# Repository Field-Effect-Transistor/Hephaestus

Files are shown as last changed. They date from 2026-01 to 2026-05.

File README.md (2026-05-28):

***

# Hephaestus: Smart Soldering Station (T12 + 858D)

**Бакалаврська кваліфікаційна робота**  
Розробка мікрокомп'ютерної системи керування двоканальною паяльною станцією з прецизійним терморегулюванням та апаратною відмовобезпекою.






## 📋 Основні можливості
*   **Два незалежні канали:** Контактний паяльник (жало T12) та компресорний термофен (858D).
*   **Прецизійна точність:** ПІД-регулювання з використанням зовнішнього 16-бітного АЦП та підсилювачів Zero-Drift.
*   **Апаратна безпека:** Електромеханічне реле із системою "самопідхвату" для захисту від термічного пробою.
*   **Багатозадачність (RTOS):** Використання FreeRTOS із витискальною багатозадачністю для суворого дотримання таймінгів алгоритму часового розділення (Time-Division).
*   **HIL Simulation:** Архітектура коду (Dependency Inversion) дозволяє компілювати та тестувати бізнес-логіку станції як нативну Linux/PC програму (Симулятор).
*   **Інтерфейс:** 1.3" OLED дисплей (u8g2) та апаратне декодування квадратурних енкодерів.

## 🛠 Технічний стек

### Апаратна частина (Hardware)
*   **MCU:** STM32F103C8T6 (ARM Cortex-M3)
*   **ADC:** ADS1115 (16-bit, I2C, ΔΣ)
*   **OpAmp:** OPA2333 / MCP6002
*   **Power:** Багаторівнева система живлення (24V, 5V, 3.3V Digital, 3.3V Analog)
*   **Drivers:** MOSFET (T12 / Турбіна), Triac BTA16 + Optocoupler (Нагрівач 220В)
*   **EDA:** KiCad 8.0

### Програмна частина (Firmware)
*   **Language:** C++17 / C
*   **Framework:** STM32 HAL / LL
*   **OS:** FreeRTOS (ARM CM3 Port / POSIX Port для симулятора)
*   **Build System:** CMake + Ninja
*   **IDE:** Visual Studio Code (C/C++ Extension Pack)

## 📂 Структура репозиторію

```text
├── firmware/
│   ├── App/             # Бізнес-логіка, Інтерфейси (C++)
│   │   ├── interfaces/  # Апаратні абстракції (Hardware Agnostic)
│   │   ├── logic/       # ПІД-регулятор, автомати станів кнопок
│   │   ├── platform/    # Реалізація інтерфейсів (STM32 HAL або PC Mocks)
│   │   └── ui/          # Керування дисплеєм (u8g2)
│   ├── Core/            # Згенерований CubeMX код (main.c, freertos.c)
│   ├── Drivers/         # STM32 HAL & CMSIS
│   └── Libs/            # Сторонні бібліотеки (u8g2, FreeRTOS POSIX)
│
├── hardware/            # Схемотехніка та плати (KiCad)
└── docs/                # Пояснювальна записка та даташити
```

## 🚀 Як зібрати проєкт

Проєкт підтримує дві цілі збірки: **Прошивка для мікроконтролера (STM32)** та **Симулятор для комп'ютера (Linux/PC)**.

### 1. Збірка Симулятора (Linux)
Симулятор компілює всю бізнес-логіку, запускає FreeRTOS поверх Pthreads операційної системи Linux та імітує датчики за допомогою об'єктів-заглушок (Mocks). Це дозволяє тестувати систему без реальної плати.

**Вимоги:** `cmake`, `ninja`, `gcc`, `g++`.

```bash
cd firmware
mkdir -p build_pc
rm -rf build_pc/* 

# Генеруємо конфігурацію для симулятора
cmake -DBUILD_SIMULATOR=ON -DCMAKE_C_COMPILER=gcc -DCMAKE_CXX_COMPILER=g++ . -G Ninja -B build_pc   

# Збираємо проєкт
ninja -C build_pc 

# Запускаємо симулятор
./build_pc/Hephaestus_Sim
```

### 2. Збірка Прошивки (STM32)
Для крос-компіляції під мікроконтролер використовується офіційний Toolchain.

**Вимоги:** `arm-none-eabi-gcc`, `cmake`, `ninja`.

```bash
cd firmware
mkdir -p build
rm -rf build/*

# Генеруємо конфігурацію для крос-компіляції
cmake -DCMAKE_TOOLCHAIN_FILE=cmake/gcc-arm-none-eabi.cmake . -G Ninja -B build

# Збираємо прошивку (.elf, .bin, .hex)
ninja -C build
```

***

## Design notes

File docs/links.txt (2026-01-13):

https://www.datasheethub.com/wp-content/uploads/2022/08/SSD1306.pdf
https://www.alldatasheet.com/datasheet-pdf/view/328702/ALPS/EC11.html
https://documentation.espressif.com/esp32-s3_datasheet_en.html
https://github.com/wagiminator/ATmega-Soldering-Station/
https://www.alldatasheet.com/datasheet-pdf/pdf/195291/MICROCHIP/MCP6002-ISLASHSN.html
https://www.alldatasheet.com/datasheet-pdf/pdf/68872/IRF/IRLZ44N.html
https://www.alldatasheet.com/datasheet-pdf/pdf/22039/STMICROELECTRONICS/BTA16.html
https://www.alldatasheet.com/datasheet-pdf/pdf/292735/TI/ADS1115.html
https://www.alldatasheet.com/datasheet-pdf/view/1082481/TI1/LM358.html
https://www.ti.com/lit/ds/symlink/ads1115.pdf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

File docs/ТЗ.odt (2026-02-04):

# ТЕХНІЧНЕ ЗАВДАННЯ

Тема: Розробка апаратно-програмного комплексу двоканальної паяльної станції з підтримкою IoT-технологій та віддаленого керування.

Мета проєкту: Розробити прецизійний інструмент для монтажу та демонтажу електронних компонентів, що поєднує функціонал контактної пайки (стандарт T12) та термоповітряної пайки (фен 858D). Забезпечити високу точність підтримки температури за рахунок використання ПІД-алгоритмів та зовнішнього АЦП. Реалізувати концепцію IoT (Internet of Things) шляхом інтеграції веб-сервера для віддаленого моніторингу телеметрії, налаштування профілів та оновлення ПЗ.

Вимоги:

1. Апаратна платформа та сумісність:
  a. Головний контролер: Побудований на базі мікроконтролера архітектури ARM Cortex-M (STM32F103) для забезпечення роботи в реальному часі (Hard Real-Time).
  b. Мережевий шлюз: Використання модуля ESP8266 (ESP-07S) для забезпечення Wi-Fi з'єднання та хостингу вебу.
  c. Периферія: Підтримка змінних картриджів типу Hakko T12 та ручки термофену типу 858D (220В + 24В фен).
  d. Інтерфейс користувача: 1.23`` OLED-дисплей та подвійні енкодери.
2. Структура системи:
  a. Модуль керування (Control Unit - STM32):
    1. ПІД-регулятор температури (окремі контури для паяльника та фена).
    2. Драйвер дисплея та обробка енкодерів.
    3. Система безпеки (Watchdog, моніторинг помилок).
    4. UART-міст для обміну командами з ESP8266.
  b. Модуль комунікації (Gateway - ESP8266):
    1. HTTP-сервер (Web UI).
    2. UART-міст для обміну командами з STM32.
    3. OTA-менеджер.
  c. Аналогово-силова частина (PCB):
    1. Блок вимірювання (ADS1115 + ОП).
    2. Силові ключі (MOSFET для DC, Triac для AC).
    3. Схема захисного відключення.
3. Технологічний стек:
  a. Вбудоване ПЗ (Firmware): Мова C/C++. Середовище розробки VS Code + PlatformIO.
  b. Операційна система: FreeRTOS для STM32 та Arduino Core/Non-OS SDK для ESP8266.
  c. Схемотехніка: Проєктування електричної схеми та друкованої плати в САПР KiCad.
  d. Протоколи обміну: I2C (для сенсорів/дисплея), UART (міжпроцесорний зв'язок).
  e. Web-frontend: HTML, CSS3, JavaScript (бібліотека Chart.js для візуалізації графіків температури).
4. Вимірювання та точність:
  a. Для мінімізації шумів та підвищення розрядності вимірювань використовувати зовнішній 16-бітний АЦП (ADS1115).
  b. Реалізувати апаратну компенсацію холодного спаю (Cold Junction Compensation) з використанням NTC-термістора в ручці паяльника.
  c. Діапазон регулювання температур: 100°C – 450°C (для паяльника), 100°C – 500°C (для фена). Похибка стабілізації не більше ±5°C.
5. Функціональність сервера (ESP8266):
  a. Відображення поточного стану (температура, потужність, статус сну) в реальному часі через WebSocket.
  b. Надання інтерфейсу для зміни коефіцієнтів ПІД (Kp, Ki, Kd) "на льоту".
  c. Логування графіків нагріву для аналізу перехідних процесів.
  d. Можливість віддаленого оновлення прошивки як ESP, так і STM32 (через UART).
6. Безпека та захист:
  a. Hardware: Реалізація схеми "самопідхвату" живлення на базі реле. При зависанні МК або аварійній ситуації живлення має фізично вимикатися до ручного перезапуску.
  b. Software: Алгоритмічний захист від перегріву (Runaway protection) — відключення нагріву, якщо температура не зростає при подачі потужності (обрив датчика).
  c. Гальванічна розв'язка ланцюгів 220В (через оптопари з Zero-Cross).

# Мінімальний життєздатний продукт (MVP)

Мета MVP: Створити повністю функціональний пристрій, здатний виконувати задачі пайки та демонтажу з керуванням через фізичні енкодери та базовим відображенням параметрів у веб-інтерфейсі.

Функціональні вимоги MVP:

1. Стабільна робота ПІД-регуляторів для обох каналів (T12 та 858D).
2. Коректна робота силової частини: керування нагрівачем фена (220В), вентилятором та паяльником (24В).
3. Реалізація режимів сну (Sleep Mode) при бездіяльності інструменту (датчик вібрації/геркон).
4. Базовий веб-інтерфейс: відображення поточної та заданої температури.
5. Робоча схема захисного реле (увімкнення/вимкнення кнопкою без фіксації).

Потенційні напрямки розвитку

Мета: Розширення можливостей для лабораторного використання та інтеграції в систему "Розумний дім".

- Інтеграція: Додавання підтримки протоколу MQTT для підключення до Home Assistant.
- Профілі пайки: Створення бібліотеки термопрофілів для різних типів припоїв та жал.
- Діагностика: Реалізація системи самодіагностики споживання струму та напруги БЖ.
- Мобільний додаток: Створення нативного додатку замість веб-інтерфейсу.

Кроки реалізації продукту

- Етап 1 (Hardware): Розробка схеми в KiCad, розведення плати, замовлення компонентів, монтаж плати (Soldering), перевірка силових вузлів.
- Етап 2 (Firmware - Low Level): Написання драйверів для STM32 (ADS1115, I2C, UART, PWM, GPIO) з використанням регістрів/HAL та FreeRTOS.
- Етап 3 (Control Logic): Реалізація та налаштування ПІД-регулятора, калібрування АЦП.
- Етап 4 (Connectivity): Розробка прошивки для ESP8266, створення веб-інтерфейсу, налаштування обміну даними між чіпами.
- Етап 5 (Integration): Збірка в корпус, фінальне тестування, написання дипломної документації.

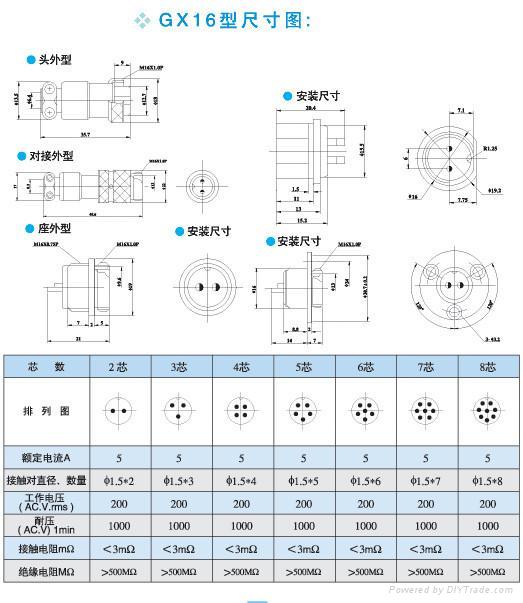
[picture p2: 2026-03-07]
docs/datasheets/GX16.jpg

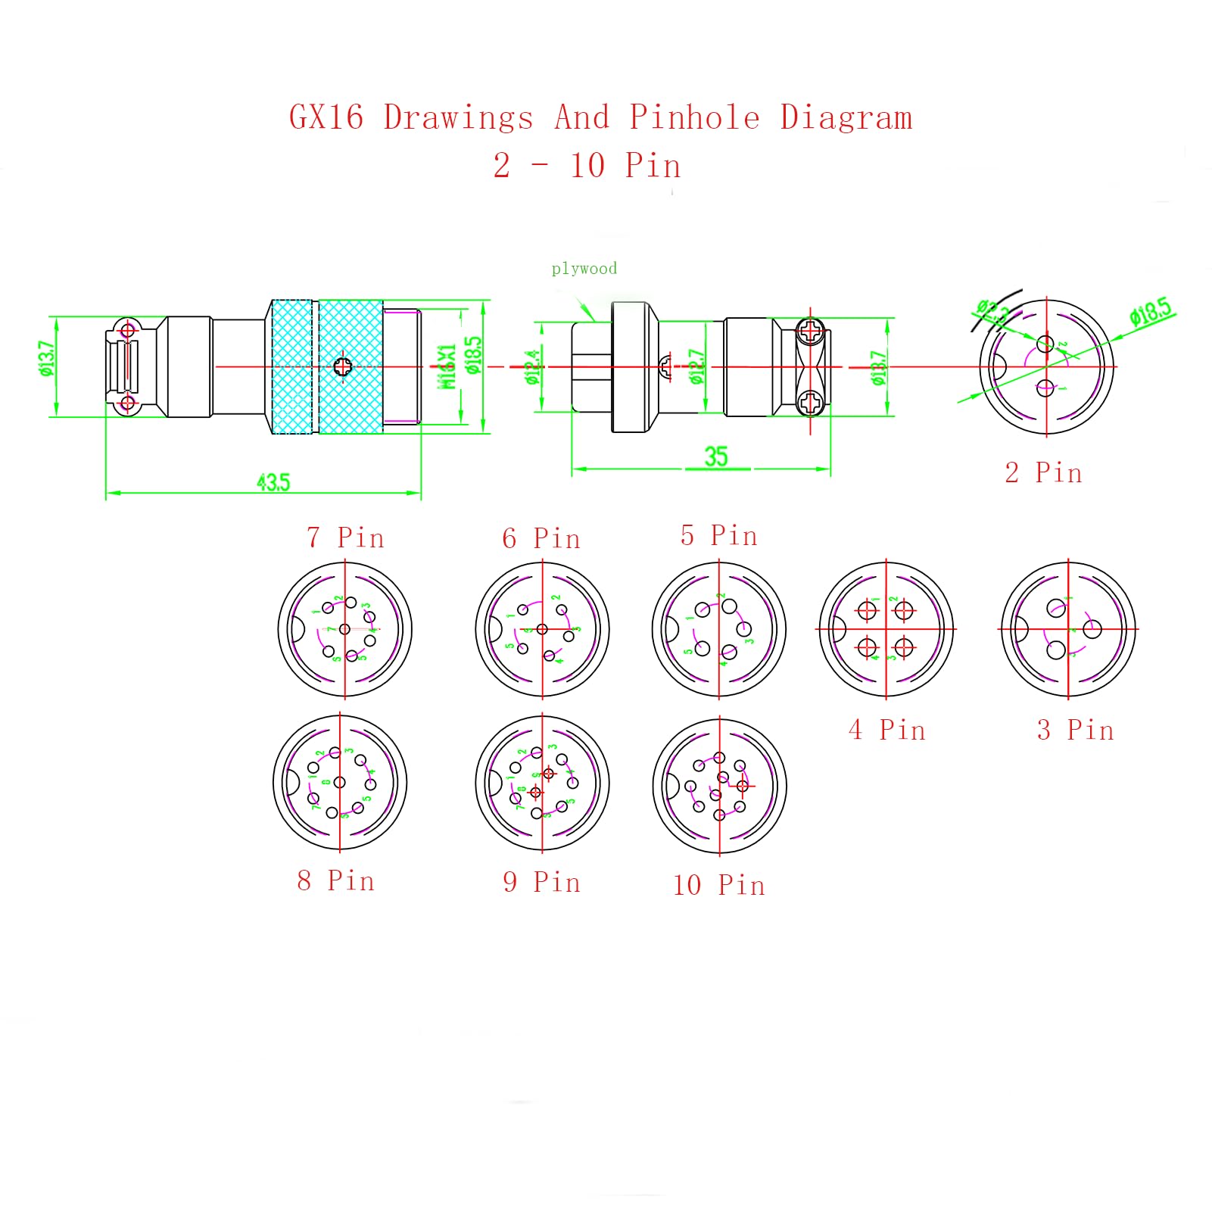
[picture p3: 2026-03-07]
docs/datasheets/71A6K6x6qkL.jpg

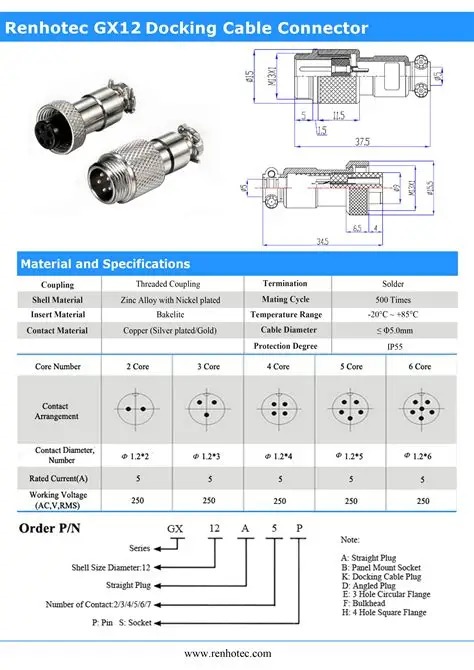
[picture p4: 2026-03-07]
docs/datasheets/OIP.webp

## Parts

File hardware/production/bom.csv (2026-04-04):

Designator | Footprint | Quantity | Value | LCSC Part #
BZ1 | Buzzer_12x9.5RM7.6 | 1 | Buzzer
C1, C12, C14, C15, C16, C17, C18, C19, C2, C20, C6, C7, C8 | 0805 | 13 | 0.1u | C14663
C10, C9 | 0805 | 2 | 22pF | C1653
C11, C21 | CP_Radial_D6.3mm_P2.50mm | 2 | 100uF
C13, C3 | CP_Radial_D5.0mm_P2.00mm | 2 | 10uF
C4 | 1206 | 1 | 10uF | C13585
C5 | 0805 | 1 | 1uF | C1634
C8_2 | CP_EIA-3216-18_Kemet-A | 1 | 22uF
D1, D2 | D_SMA | 2 | SS54 | C22452
D3 | D_DO-35_SOD27_P2.54mm_Vertical_AnodeUp | 1 | BZT52C12
D4 | D_SOD-123F | 1 | 1N4148 | C2128
D5 | D_DO-35_SOD27_P2.54mm_Vertical_AnodeUp | 1 | BZT52C3V3
D6, D7, D8 | 0805 | 3 | LED | C2286
GX12 | GX-12-5 | 1 | Soldering Iron
GX16 | GX-16-8 | 1 | Hot Air
J1 | TerminalBlock_MaiXu_MX126-5.0-03P_1x03_P5.00mm | 1 | AC Screw Terminal
J10 | TerminalBlock_MaiXu_MX126-5.0-03P_1x03_P5.00mm | 1 | Power
J11, J9 | PinHeader_1x02_P2.54mm_Vertical | 2 | Logic
J12 | PinHeader_1x04_P2.54mm_Vertical | 1 | SWD
J13 | TerminalBlock_MaiXu_MX126-5.0-02P_1x02_P5.00mm | 1 | Relay Contact
J14 | TerminalBlock_MaiXu_MX126-5.0-02P_1x02_P5.00mm | 1 | Relay Coil
J2 | PinHeader_1x05_P2.54mm_Vertical | 1 | Iron Encoder
J3 | PinHeader_1x05_P2.54mm_Vertical | 1 | Hot Air Encoder
J4 | PinHeader_1x04_P2.54mm_Vertical | 1 | OLED
J5 | TerminalBlock_MaiXu_MX126-5.0-02P_1x02_P5.00mm | 1 | High Voltage
J6 | PinHeader_1x04_P2.54mm_Vertical | 1 | UART
J7 | PinHeader_1x03_P2.54mm_Vertical | 1 | STM BOOT
J8 | TerminalBlock_MaiXu_MX126-5.0-03P_1x03_P5.00mm | 1 | +5V
JP1 | PinHeader_1x03_P2.54mm_Vertical | 1 | Jumper_2_Open
Q1, Q4 | TO-220-3_Vertical | 2 | IRLZ44N
Q2, Q3, Q5 | TO-92_Inline | 3 | 2N2222 | C2146
Q7 | TO-220-3_Vertical | 1 | BTA16-600B
R1, R3 | 0805 | 2 | 300 | C23025
R10, R16 | R_Axial_DIN0207_L6.3mm_D2.5mm_P7.62mm_Horizontal | 2 | 3k
R11, R39 | 0805 | 2 | 2.2k | C4190
R12, R15, R17, R18, R19, R20, R22, R23, R29, R30, R31, R32, R33, R34, R35, R38, R41, R42 | 0805 | 18 | 1k | C21190
R13, R14, R2, R21, R26, R28, R36, R37, R40, R6, R7, R8, R9 | 0805 | 13 | 10k | C25804
R24, R27 | 0805 | 2 | 100k | C25803
R25 | 0805 | 1 | 200k | C25811
R4, R5 | R_Axial_DIN0309_L9.0mm_D3.2mm_P12.70mm_Horizontal | 2 | 390/0.5W
SW1 | SW_PUSH_6mm_H8mm | 1 | SW_SPST
SW2 | TerminalBlock_MaiXu_MX126-5.0-02P_1x02_P5.00mm | 1 | SW_SPST
SW3 | PinHeader_1x02_P2.54mm_Vertical | 1 | SW_SPST
U1 | DIP-6_W7.62mm_LongPads | 1 | MOC3063M
U2, U4 | SOT-223-3_TabPin2 | 2 | AMS1117-3.3 | C6186
U5 | LQFP-48_7x7mm_P0.5mm | 1 | STM32F103C8Tx
U6 | SOIC-8_3.9x4.9mm_P1.27mm | 1 | MCP6002-xSN
U7 | MSOP-10_3x3mm_P0.5mm | 1 | ADS1115
Y1 | Crystal_SMD_5032-2Pin_5.0x3.2mm | 1 | X50328MSB2GI | C115962

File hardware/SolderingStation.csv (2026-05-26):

Reference | Value | Qty | LCSC | Footprint
C9,C10 | 22pF | 2 | C1653 | Capacitor_SMD:C_0805_2012Metric_Pad1.18x1.45mm_HandSolder
C1,C2,C6,C7,C8,C12,C14,C15,C16,C17,C18,C19,C20 | 0.1u | 13 | C14663 | Capacitor_SMD:C_0805_2012Metric_Pad1.18x1.45mm_HandSolder
C5 | 1uF | 1 | C1634 | Capacitor_SMD:C_0805_2012Metric_Pad1.18x1.45mm_HandSolder
C3,C13 | 10uF | 2 |  | Capacitor_THT:CP_Radial_D5.0mm_P2.00mm
C4 | 10uF | 1 | C13585 | Capacitor_SMD:C_1206_3216Metric
C11,C21 | 100uF | 2 |  | Capacitor_THT:CP_Radial_D6.3mm_P2.50mm
R1,R3 | 300 | 2 | C23025 | Resistor_SMD:R_0805_2012Metric_Pad1.20x1.40mm_HandSolder
R12,R15,R17,R18,R19,R20,R22,R23,R29,R30,R31,R32,R33,R34,R35,R38,R41,R42 | 1k | 18 | C21190 | Resistor_SMD:R_0805_2012Metric_Pad1.20x1.40mm_HandSolder
R11,R39 | 2.2k | 2 | C4190 | Resistor_SMD:R_0805_2012Metric_Pad1.20x1.40mm_HandSolder
R10,R16 | 3k | 2 |  | Resistor_THT:R_Axial_DIN0207_L6.3mm_D2.5mm_P7.62mm_Horizontal
R2,R6,R7,R8,R9,R13,R14,R21,R26,R28,R36,R37,R40 | 10k | 13 | C25804 | Resistor_SMD:R_0805_2012Metric_Pad1.20x1.40mm_HandSolder
R24,R27 | 100k | 2 | C25803 | Resistor_SMD:R_0805_2012Metric_Pad1.20x1.40mm_HandSolder
R25 | 200k | 1 | C25811 | Resistor_SMD:R_0805_2012Metric_Pad1.20x1.40mm_HandSolder
J8 | +5V | 1 |  | TerminalBlock:TerminalBlock_MaiXu_MX126-5.0-03P_1x03_P5.00mm
D4 | 1N4148 | 1 | C2128 | Diode_SMD:D_SOD-123F
Q2,Q3,Q5 | 2N2222 | 3 | C2146 | Package_TO_SOT_THT:TO-92_Inline
R4,R5 | 390/0.5W | 2 |  | Resistor_THT:R_Axial_DIN0309_L9.0mm_D3.2mm_P12.70mm_Horizontal
J1 | AC Screw Terminal | 1 |  | TerminalBlock:TerminalBlock_MaiXu_MX126-5.0-03P_1x03_P5.00mm
U7 | ADS1115 | 1 |  | Package_SO:MSOP-10_3x3mm_P0.5mm
U2,U4 | AMS1117-3.3 | 2 | C6186 | Package_TO_SOT_SMD:SOT-223-3_TabPin2
Q7 | BTA16-600B | 1 |  | Package_TO_SOT_THT:TO-220-3_Vertical
BZ1 | Buzzer | 1 |  | Buzzer_Beeper:Buzzer_12x9.5RM7.6
D3 | BZT52C12 | 1 |  | Diode_THT:D_DO-35_SOD27_P2.54mm_Vertical_AnodeUp
D5 | BZT52C3V3 | 1 |  | Diode_THT:D_DO-35_SOD27_P2.54mm_Vertical_AnodeUp
J5 | High Voltage | 1 |  | TerminalBlock:TerminalBlock_MaiXu_MX126-5.0-02P_1x02_P5.00mm
GX16 | Hot Air | 1 |  | SolderingStationLib:GX-16-8
J3 | Hot Air Encoder | 1 |  | Connector_PinHeader_2.54mm:PinHeader_1x05_P2.54mm_Vertical
Q1,Q4 | IRLZ44N | 2 |  | Package_TO_SOT_THT:TO-220-3_Vertical
J2 | Iron Encoder | 1 |  | Connector_PinHeader_2.54mm:PinHeader_1x05_P2.54mm_Vertical
JP1 | Jumper_2_Open | 1 |  | Connector_PinHeader_2.54mm:PinHeader_1x03_P2.54mm_Vertical
D6,D7,D8 | LED | 3 | C2286 | LED_SMD:LED_0805_2012Metric_Pad1.15x1.40mm_HandSolder
J9,J11 | Logic | 2 |  | Connector_PinHeader_2.54mm:PinHeader_1x02_P2.54mm_Vertical
U6 | MCP6002-xSN | 1 |  | Package_SO:SOIC-8_3.9x4.9mm_P1.27mm
U1 | MOC3063M | 1 |  | Package_DIP:DIP-6_W7.62mm_LongPads
J4 | OLED | 1 |  | Connector_PinHeader_2.54mm:PinHeader_1x04_P2.54mm_Vertical
J10 | Power | 1 |  | TerminalBlock:TerminalBlock_MaiXu_MX126-5.0-03P_1x03_P5.00mm
J14 | Relay Coil | 1 |  | TerminalBlock:TerminalBlock_MaiXu_MX126-5.0-02P_1x02_P5.00mm
J13 | Relay Contact | 1 |  | TerminalBlock:TerminalBlock_MaiXu_MX126-5.0-02P_1x02_P5.00mm
K1 | Relay-NO | 1 |  | TerminalBlock:TerminalBlock_MaiXu_MX126-5.0-04P_1x04_P5.00mm
GX12 | Soldering Iron | 1 |  | SolderingStationLib:GX-12-5
D1,D2 | SS54 | 2 | C22452 | Diode_SMD:D_SMA
J7 | STM BOOT | 1 |  | Connector_PinHeader_2.54mm:PinHeader_1x03_P2.54mm_Vertical
U5 | STM32F103C8Tx | 1 |  | Package_QFP:LQFP-48_7x7mm_P0.5mm
SW1 | SW_SPST | 1 |  | Button_Switch_THT:SW_PUSH_6mm_H8mm
SW2 | SW_SPST | 1 |  | TerminalBlock:TerminalBlock_MaiXu_MX126-5.0-02P_1x02_P5.00mm
SW3 | SW_SPST | 1 |  | Connector_PinHeader_2.54mm:PinHeader_1x02_P2.54mm_Vertical
J12 | SWD | 1 |  | Connector_PinHeader_2.54mm:PinHeader_1x04_P2.54mm_Vertical
J6 | UART | 1 |  | Connector_PinHeader_2.54mm:PinHeader_1x04_P2.54mm_Vertical
Y1 | X50328MSB2GI | 1 | C115962 | Crystal:Crystal_SMD_5032-2Pin_5.0x3.2mm

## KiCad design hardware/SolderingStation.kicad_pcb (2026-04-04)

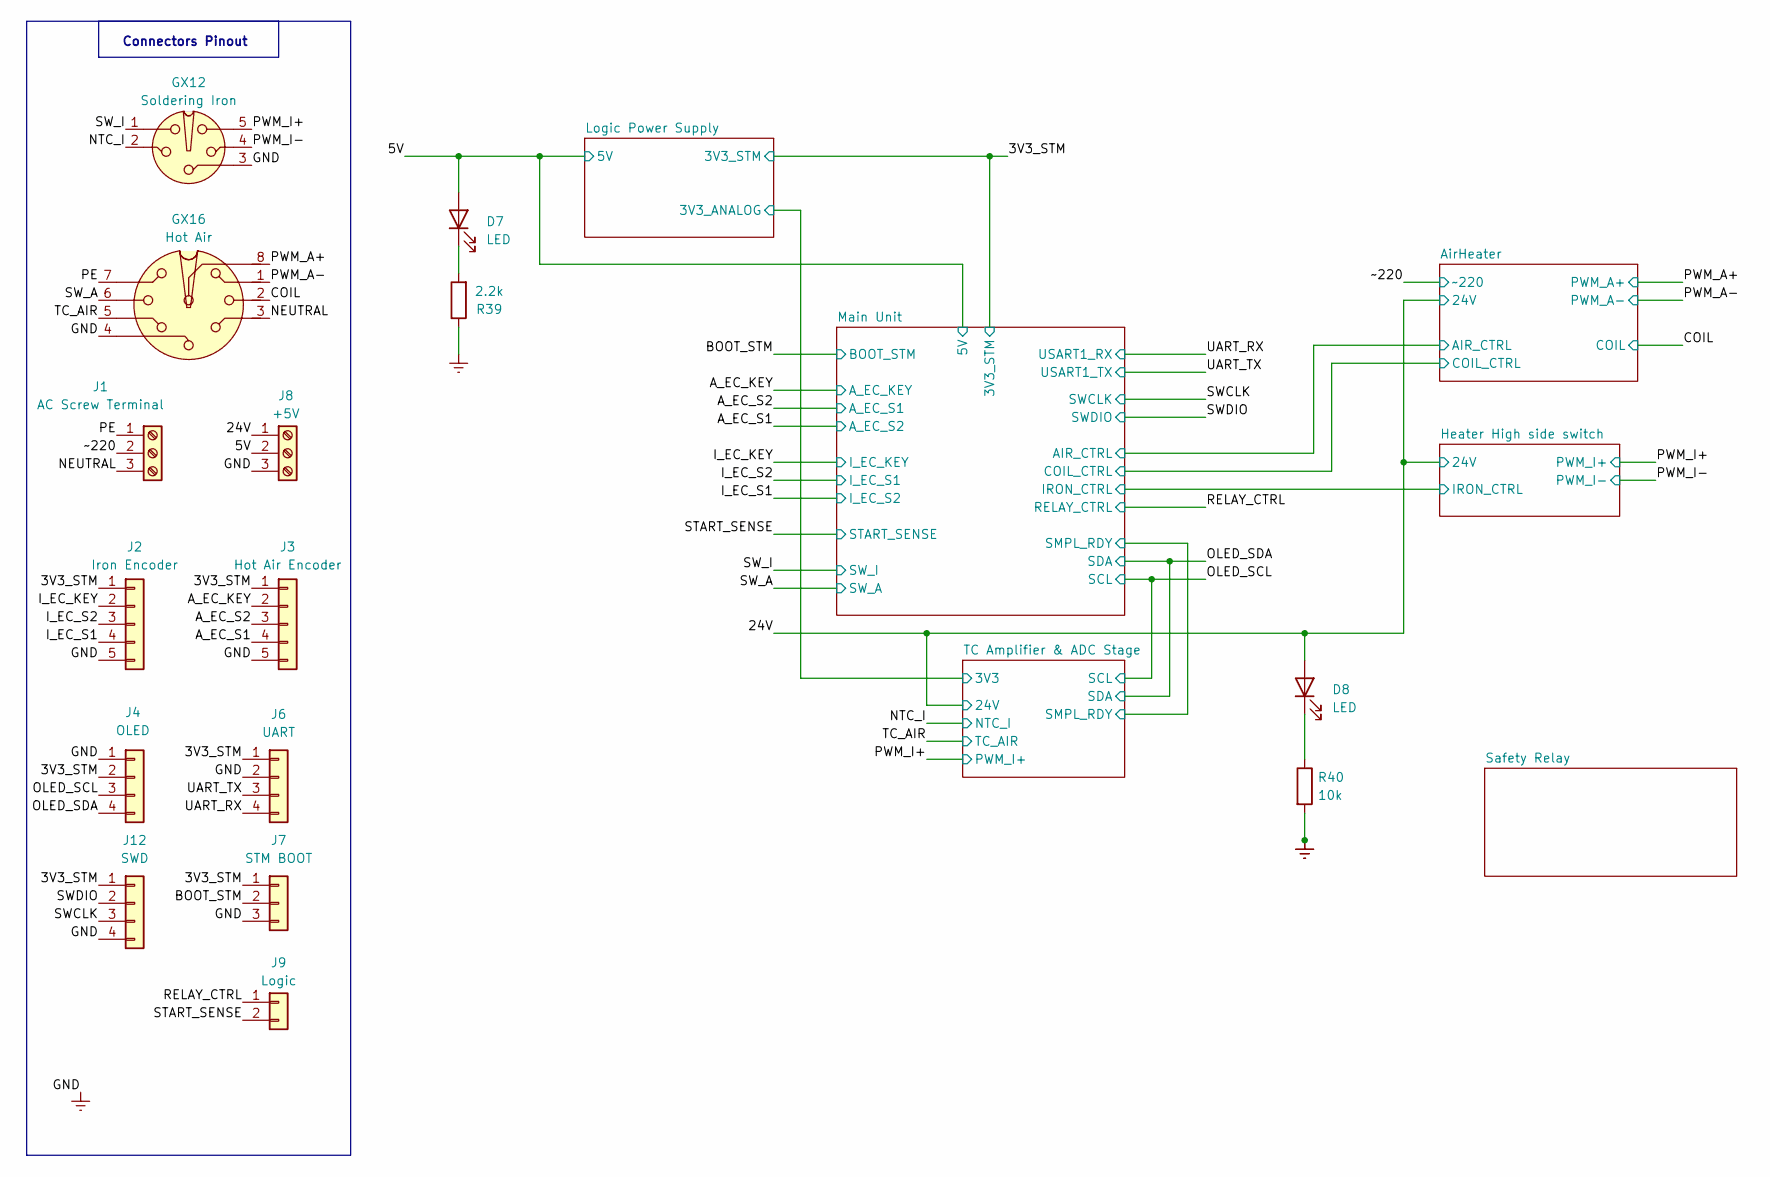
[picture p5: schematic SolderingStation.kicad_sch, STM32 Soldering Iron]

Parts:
D7, D8: LED; LED_0805_2012Metric_Pad1.15x1.40mm_HandSolder; LCSC C2286
GX12: Soldering Iron; GX-12-5
GX16: Hot Air; GX-16-8
J1: AC Screw Terminal; TerminalBlock_MaiXu_MX126-5.0-03P_1x03_P5.00mm
J2: Iron Encoder; PinHeader_1x05_P2.54mm_Vertical
J3: Hot Air Encoder; PinHeader_1x05_P2.54mm_Vertical
J4: OLED; PinHeader_1x04_P2.54mm_Vertical
J6: UART; PinHeader_1x04_P2.54mm_Vertical
J7: STM BOOT; PinHeader_1x03_P2.54mm_Vertical
J8: +5V; TerminalBlock_MaiXu_MX126-5.0-03P_1x03_P5.00mm
J9: Logic; PinHeader_1x02_P2.54mm_Vertical
J12: SWD; PinHeader_1x04_P2.54mm_Vertical
R39: 2.2k; R_0805_2012Metric_Pad1.20x1.40mm_HandSolder; LCSC C4190
R40: 10k; R_0805_2012Metric_Pad1.20x1.40mm_HandSolder; LCSC C25804

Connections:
/3V3_STM: J2.1, J3.1, J4.2, J6.1, J7.1, J12.1; also elsewhere on the board
/5V: D7.2 (A), J8.2; also elsewhere on the board
/24V: D8.2 (A), GX16.8, J8.1; also elsewhere on the board
/A_EC_KEY: J3.2; also elsewhere on the board
/A_EC_S1: J3.4; also elsewhere on the board
/A_EC_S2: J3.3; also elsewhere on the board
/BOOT_STM: J7.2; also elsewhere on the board
/COIL: GX16.2; also elsewhere on the board
/I_EC_KEY: J2.2; also elsewhere on the board
/I_EC_S1: J2.4; also elsewhere on the board
/I_EC_S2: J2.3; also elsewhere on the board
/NEUTRAL: GX16.3, J1.3
/NTC_I: GX12.2; also elsewhere on the board
/OLED_SCL: J4.3; also elsewhere on the board
/OLED_SDA: J4.4; also elsewhere on the board
/PE: GX16.7, J1.1
/PWM_A-: GX16.1; also elsewhere on the board
/PWM_I+: GX12.5; also elsewhere on the board
/RELAY_CTRL: J9.1; also elsewhere on the board
/START_SENSE: J9.2; also elsewhere on the board
/SWCLK: J12.3; also elsewhere on the board
/SWDIO: J12.2; also elsewhere on the board
/SW_A: GX16.6; also elsewhere on the board
/SW_I: GX12.1; also elsewhere on the board
/TC_AIR: GX16.5; also elsewhere on the board
/UART_RX: J6.4; also elsewhere on the board
/UART_TX: J6.3; also elsewhere on the board
/~220: J1.2; also elsewhere on the board
GNDREF: GX12.3, GX12.4, GX16.4, J2.5, J3.5, J4.1, J6.2, J7.3, J8.3, J12.4, R39.1, R40.2; also elsewhere on the board
unnamed: D7.1 (K), R39.2
unnamed: D8.1 (K), R40.1

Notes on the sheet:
Connectors Pinout

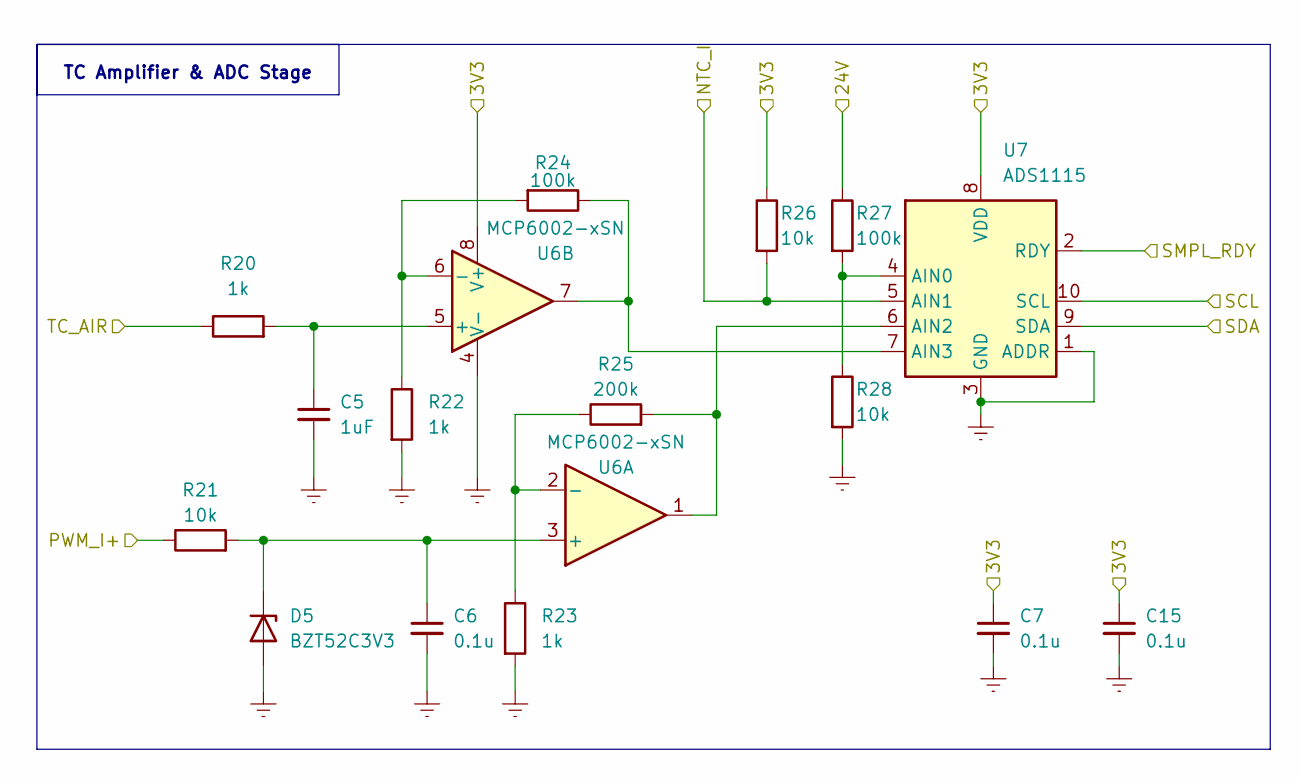
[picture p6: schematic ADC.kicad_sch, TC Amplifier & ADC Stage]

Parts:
C5: 1uF; C_0805_2012Metric_Pad1.18x1.45mm_HandSolder; LCSC C1634
C6, C7, C15: 0.1u; C_0805_2012Metric_Pad1.18x1.45mm_HandSolder; LCSC C14663
D5: BZT52C3V3; D_DO-35_SOD27_P2.54mm_Vertical_AnodeUp
R20, R22, R23: 1k; R_0805_2012Metric_Pad1.20x1.40mm_HandSolder; LCSC C21190
R21, R26, R28: 10k; R_0805_2012Metric_Pad1.20x1.40mm_HandSolder; LCSC C25804
R24, R27: 100k; R_0805_2012Metric_Pad1.20x1.40mm_HandSolder; LCSC C25803
R25: 200k; R_0805_2012Metric_Pad1.20x1.40mm_HandSolder; LCSC C25811
U6: MCP6002-xSN; SOIC-8_3.9x4.9mm_P1.27mm
U7: ADS1115; MSOP-10_3x3mm_P0.5mm

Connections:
/24V: R27.1; also elsewhere on the board
/Logic Power Supply/3V3_ANALOG: C7.1, C15.1, R26.1, U6.8 (V+), U7.8 (VDD); also elsewhere on the board
/Main Unit/SMPL_RDY: U7.2 (RDY); also elsewhere on the board
/NTC_I: R26.2, U7.5 (AIN1); also elsewhere on the board
/OLED_SCL: U7.10 (SCL); also elsewhere on the board
/OLED_SDA: U7.9 (SDA); also elsewhere on the board
/PWM_I+: R21.1; also elsewhere on the board
/TC_AIR: R20.1; also elsewhere on the board
GNDREF: C5.2, C6.2, C7.2, C15.2, D5.2 (A), R22.2, R23.2, R28.2, U6.4 (V-), U7.1 (ADDR), U7.3 (GND); also elsewhere on the board
unnamed: C6.1, D5.1 (K), R21.2, U6.3 (+)
unnamed: R23.1, R25.1, U6.2 (-)
unnamed: C5.1, R20.2, U6.5 (+)
unnamed: R22.1, R24.2, U6.6 (-)
unnamed: R27.2, R28.1, U7.4 (AIN0)
unnamed: R25.2, U6.1, U7.6 (AIN2)
unnamed: R24.1, U6.7, U7.7 (AIN3)

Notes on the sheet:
TC Amplifier & ADC Stage

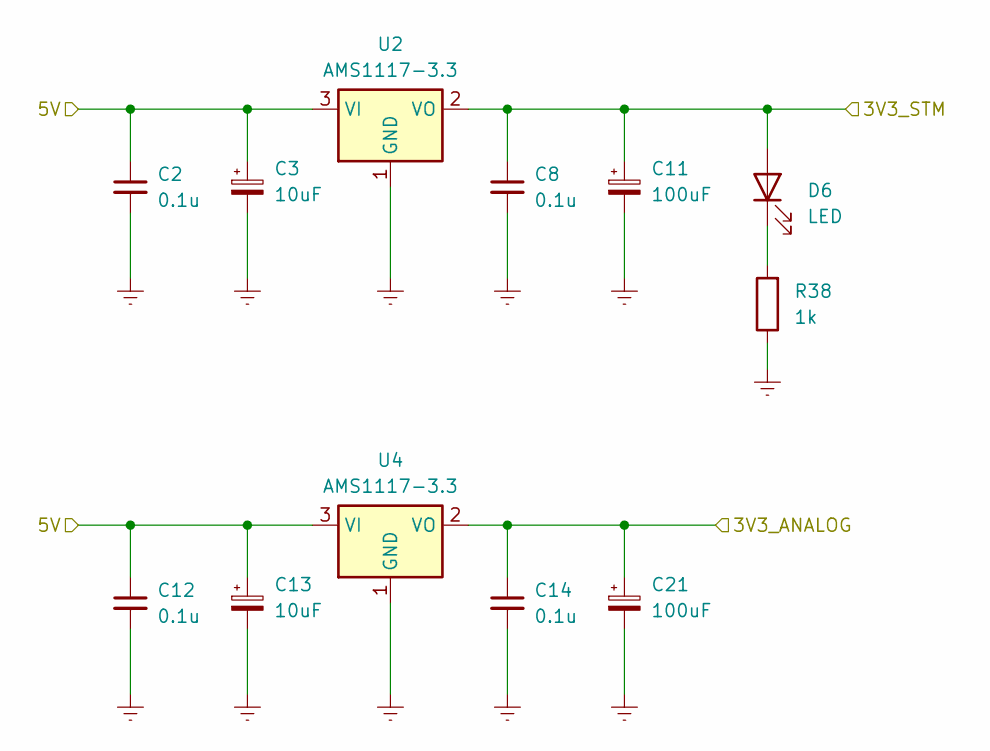
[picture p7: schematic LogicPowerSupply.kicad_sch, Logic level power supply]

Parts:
C2, C8, C12, C14: 0.1u; C_0805_2012Metric_Pad1.18x1.45mm_HandSolder; LCSC C14663
C3, C13: 10uF; CP_Radial_D5.0mm_P2.00mm
C11, C21: 100uF; CP_Radial_D6.3mm_P2.50mm
D6: LED; LED_0805_2012Metric_Pad1.15x1.40mm_HandSolder; LCSC C2286
R38: 1k; R_0805_2012Metric_Pad1.20x1.40mm_HandSolder; LCSC C21190
U2, U4: AMS1117-3.3; SOT-223-3_TabPin2; LCSC C6186

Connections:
/3V3_STM: C8.1, C11.1, D6.2 (A), U2.2 (VO); also elsewhere on the board
/5V: C2.1, C3.1, C12.1, C13.1, U2.3 (VI), U4.3 (VI); also elsewhere on the board
/Logic Power Supply/3V3_ANALOG: C14.1, C21.1, U4.2 (VO); also elsewhere on the board
GNDREF: C2.2, C3.2, C8.2, C11.2, C12.2, C13.2, C14.2, C21.2, R38.1, U2.1 (GND), U4.1 (GND); also elsewhere on the board
unnamed: D6.1 (K), R38.2

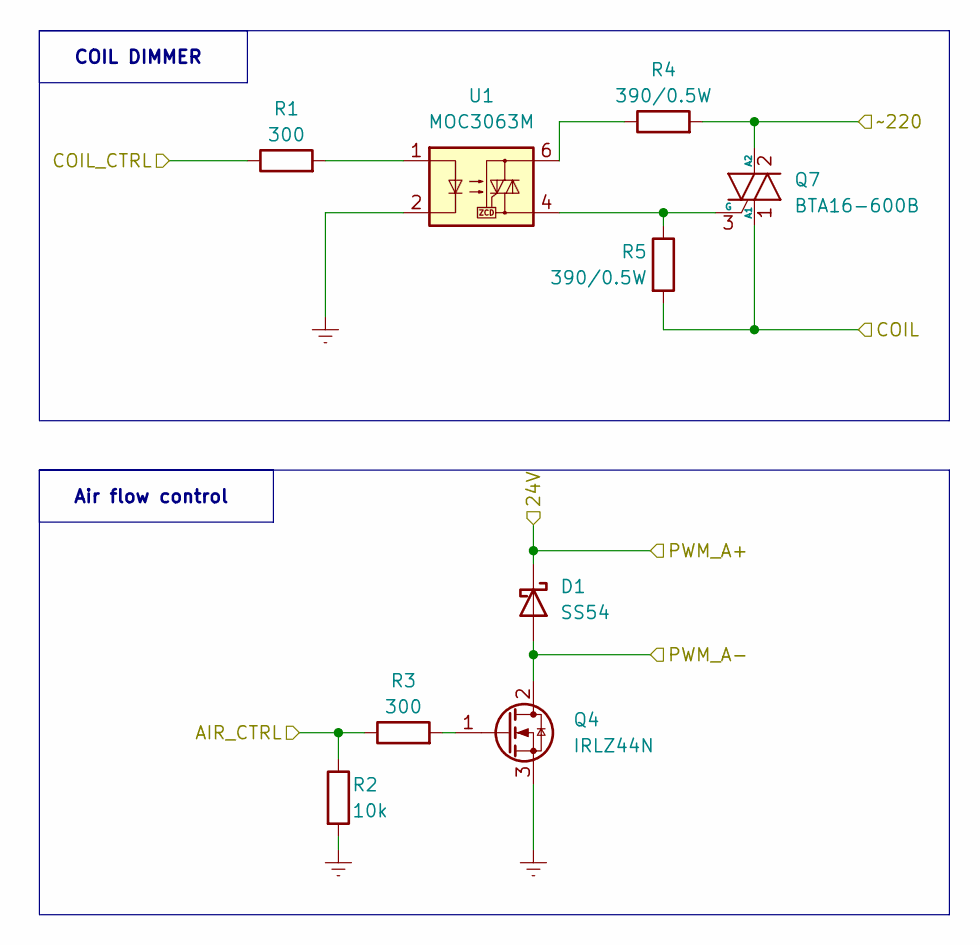
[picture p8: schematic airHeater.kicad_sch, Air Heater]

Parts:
D1: SS54; D_SMA; LCSC C22452
Q4: IRLZ44N; TO-220-3_Vertical
Q7: BTA16-600B; TO-220-3_Vertical
R1, R3: 300; R_0805_2012Metric_Pad1.20x1.40mm_HandSolder; LCSC C23025
R2: 10k; R_0805_2012Metric_Pad1.20x1.40mm_HandSolder; LCSC C25804
R4, R5: 390/0.5W; R_Axial_DIN0309_L9.0mm_D3.2mm_P12.70mm_Horizontal
U1: MOC3063M; DIP-6_W7.62mm_LongPads

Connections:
/24V: D1.1 (K); also elsewhere on the board
/AirHeater/AIR_CTRL: R2.1, R3.1; also elsewhere on the board
/AirHeater/COIL_CTRL: R1.1; also elsewhere on the board
/COIL: Q7.1 (A1), R5.2; also elsewhere on the board
/PWM_A-: D1.2 (A), Q4.2 (D); also elsewhere on the board
/~220: Q7.2 (A2), R4.2; also elsewhere on the board
GNDREF: Q4.3 (S), R2.2, U1.2; also elsewhere on the board
unnamed: Q4.1 (G), R3.2
unnamed: Q7.3 (G), R5.1, U1.4
unnamed: R1.2, U1.1
unnamed: R4.1, U1.6

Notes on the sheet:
COIL DIMMER
Air flow control

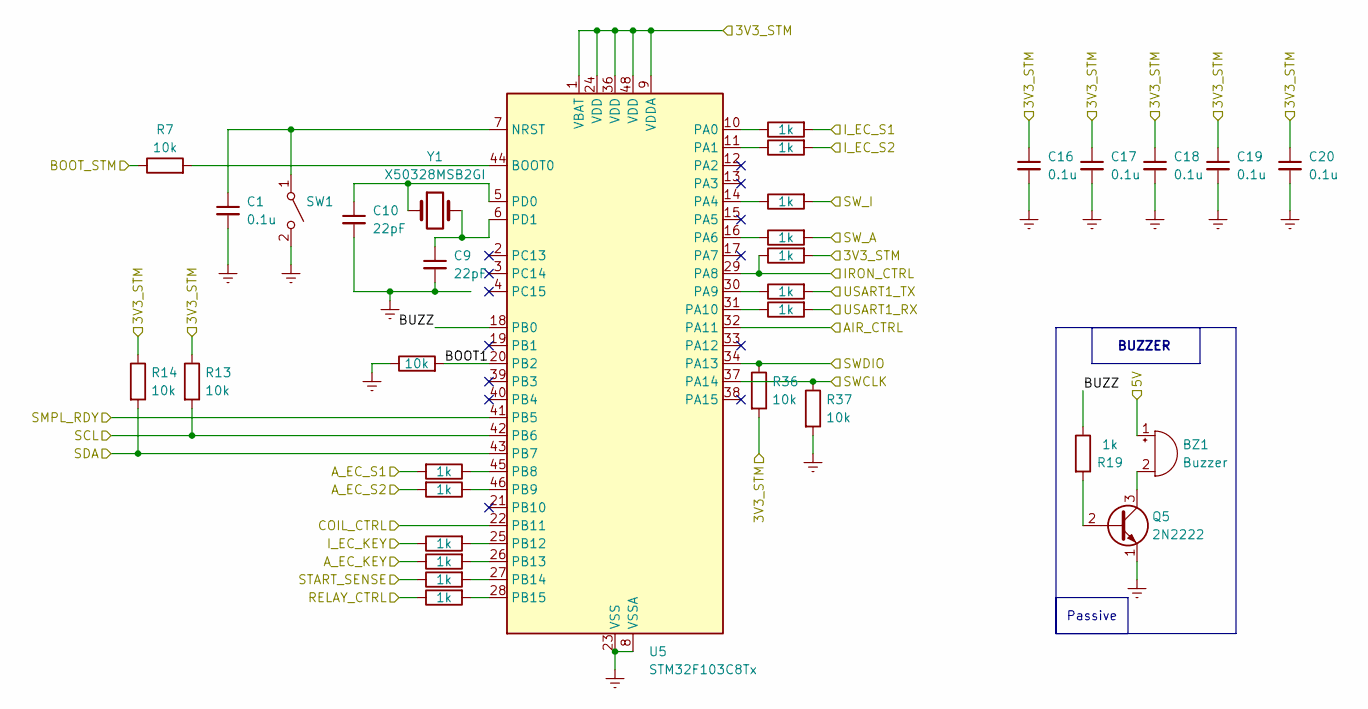
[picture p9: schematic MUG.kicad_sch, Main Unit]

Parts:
BZ1: Buzzer; Buzzer_12x9.5RM7.6
C1, C16, C17, C18, C19, C20: 0.1u; C_0805_2012Metric_Pad1.18x1.45mm_HandSolder; LCSC C14663
C9, C10: 22pF; C_0805_2012Metric_Pad1.18x1.45mm_HandSolder; LCSC C1653
Q5: 2N2222; TO-92_Inline; LCSC C2146
R6, R7, R13, R14, R36, R37: 10k; R_0805_2012Metric_Pad1.20x1.40mm_HandSolder; LCSC C25804
R12, R15, R17, R18, R19, R29, R30, R31, R32, R33, R34, R35, R41, R42: 1k; R_0805_2012Metric_Pad1.20x1.40mm_HandSolder; LCSC C21190
SW1: SW_SPST; SW_PUSH_6mm_H8mm
U5: STM32F103C8Tx; LQFP-48_7x7mm_P0.5mm
Y1: X50328MSB2GI; Crystal_SMD_5032-2Pin_5.0x3.2mm; LCSC C115962

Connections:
/3V3_STM: C16.1, C17.1, C18.1, C19.1, C20.1, R13.1, R14.1, R15.2, R36.2, U5.1 (VBAT), U5.9 (VDDA), U5.24 (VDD), U5.36 (VDD), U5.48 (VDD); also elsewhere on the board
/5V: BZ1.1 (+); also elsewhere on the board
/A_EC_KEY: R30.1; also elsewhere on the board
/A_EC_S1: R32.2; also elsewhere on the board
/A_EC_S2: R31.2; also elsewhere on the board
/AirHeater/AIR_CTRL: U5.32 (PA11); also elsewhere on the board
/AirHeater/COIL_CTRL: U5.22 (PB11); also elsewhere on the board
/BOOT_STM: R7.1; also elsewhere on the board
/Heater High side switch/IRON_CTRL: R15.1, U5.29 (PA8); also elsewhere on the board
/I_EC_KEY: R29.1; also elsewhere on the board
/I_EC_S1: R18.2; also elsewhere on the board
/I_EC_S2: R17.2; also elsewhere on the board
/Main Unit/BOOT1: R6.2, U5.20 (PB2)
/Main Unit/BUZZ: R19.1, U5.18 (PB0)
/Main Unit/SMPL_RDY: U5.41 (PB5); also elsewhere on the board
/OLED_SCL: R13.2, U5.42 (PB6); also elsewhere on the board
/OLED_SDA: R14.2, U5.43 (PB7); also elsewhere on the board
/RELAY_CTRL: R33.1; also elsewhere on the board
/START_SENSE: R12.1; also elsewhere on the board
/SWCLK: R37.1, U5.37 (PA14); also elsewhere on the board
/SWDIO: R36.1, U5.34 (PA13); also elsewhere on the board
/SW_A: R34.2; also elsewhere on the board
/SW_I: R35.2; also elsewhere on the board
/UART_RX: R42.2; also elsewhere on the board
/UART_TX: R41.2; also elsewhere on the board
GNDREF: C1.2, C9.2, C10.2, C16.2, C17.2, C18.2, C19.2, C20.2, Q5.1 (E), R6.1, R37.2, SW1.2 (B), U5.8 (VSSA), U5.23 (VSS), U5.35 (VSS), U5.47 (VSS); also elsewhere on the board
unnamed: BZ1.2 (-), Q5.3 (C)
unnamed: Q5.2 (B), R19.2
unnamed: C1.1, SW1.1 (A), U5.7 (NRST)
unnamed: R7.2, U5.44 (BOOT0)
unnamed: R17.1, U5.10 (PA0)
unnamed: R18.1, U5.11 (PA1)
unnamed: R35.1, U5.14 (PA4)
unnamed: R34.1, U5.16 (PA6)
unnamed: R41.1, U5.30 (PA9)
unnamed: R42.1, U5.31 (PA10)
unnamed: R31.1, U5.45 (PB8)
unnamed: R32.1, U5.46 (PB9)
unnamed: R29.2, U5.25 (PB12)
unnamed: R30.2, U5.26 (PB13)
unnamed: R12.2, U5.27 (PB14)
unnamed: R33.2, U5.28 (PB15)
unnamed: C10.1, U5.5 (PD0), Y1.1
unnamed: C9.1, U5.6 (PD1), Y1.2

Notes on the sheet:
Passive
BUZZER

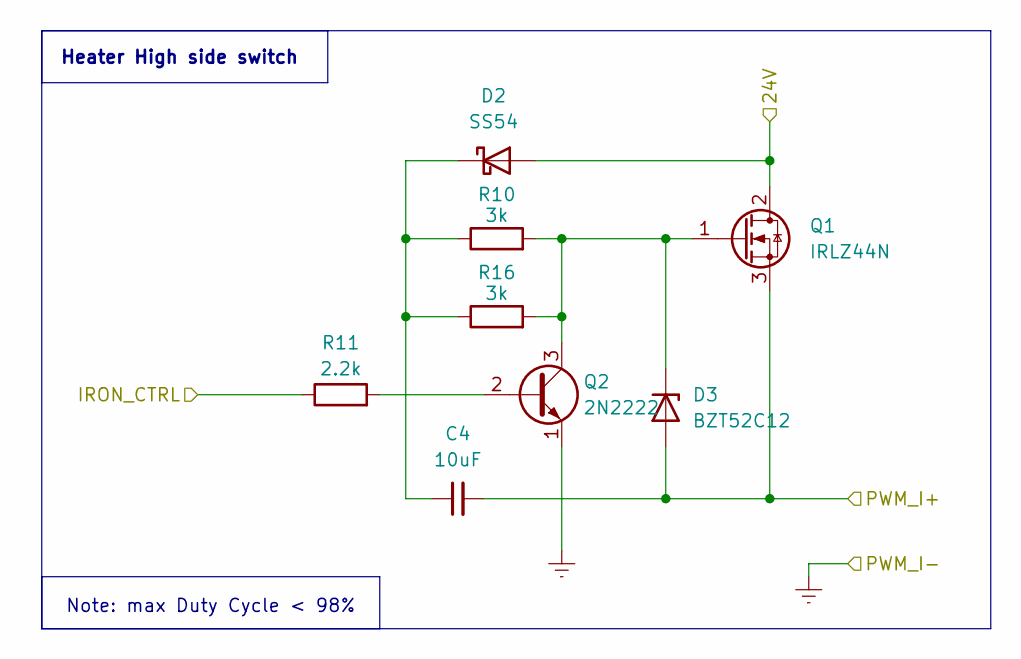
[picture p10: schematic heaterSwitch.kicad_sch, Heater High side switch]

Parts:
C4: 10uF; C_1206_3216Metric; LCSC C13585
D2: SS54; D_SMA; LCSC C22452
D3: BZT52C12; D_DO-35_SOD27_P2.54mm_Vertical_AnodeUp
Q1: IRLZ44N; TO-220-3_Vertical
Q2: 2N2222; TO-92_Inline; LCSC C2146
R10, R16: 3k; R_Axial_DIN0207_L6.3mm_D2.5mm_P7.62mm_Horizontal
R11: 2.2k; R_0805_2012Metric_Pad1.20x1.40mm_HandSolder; LCSC C4190

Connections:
/24V: D2.2 (A), Q1.2 (D); also elsewhere on the board
/Heater High side switch/IRON_CTRL: R11.1; also elsewhere on the board
/PWM_I+: C4.2, D3.2 (A), Q1.3 (S); also elsewhere on the board
GNDREF: Q2.1 (E); also elsewhere on the board
unnamed: C4.1, D2.1 (K), R10.1, R16.1
unnamed: D3.1 (K), Q1.1 (G), Q2.3 (C), R10.2, R16.2
unnamed: Q2.2 (B), R11.2

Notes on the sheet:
Note: max Duty Cycle < 98%
Heater High side switch

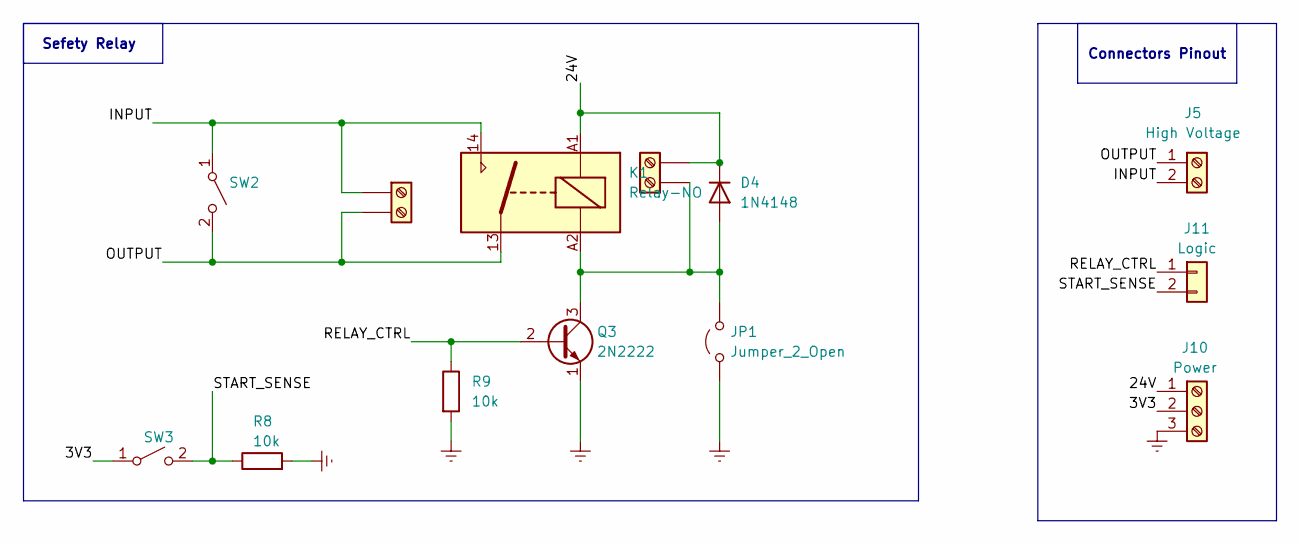
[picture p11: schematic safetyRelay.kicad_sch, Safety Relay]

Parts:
D4: 1N4148; D_SOD-123F; LCSC C2128
J5: High Voltage; TerminalBlock_MaiXu_MX126-5.0-02P_1x02_P5.00mm
J10: Power; TerminalBlock_MaiXu_MX126-5.0-03P_1x03_P5.00mm
J11: Logic; PinHeader_1x02_P2.54mm_Vertical
J13: Relay Contact; TerminalBlock_MaiXu_MX126-5.0-02P_1x02_P5.00mm
J14: Relay Coil; TerminalBlock_MaiXu_MX126-5.0-02P_1x02_P5.00mm
JP1: Jumper_2_Open; PinHeader_1x03_P2.54mm_Vertical
K1: Relay-NO; TerminalBlock_MaiXu_MX126-5.0-04P_1x04_P5.00mm
Q3: 2N2222; TO-92_Inline; LCSC C2146
R8, R9: 10k; R_0805_2012Metric_Pad1.20x1.40mm_HandSolder; LCSC C25804
SW2: SW_SPST; TerminalBlock_MaiXu_MX126-5.0-02P_1x02_P5.00mm
SW3: SW_SPST; PinHeader_1x02_P2.54mm_Vertical

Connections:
/Safety Relay/3V3: J10.2, SW3.1 (A)
/Safety Relay/24V: D4.1 (K), J10.1, J14.2, K1.A1
/Safety Relay/INPUT: J5.2, J13.1, K1.14, SW2.1 (A)
/Safety Relay/OUTPUT: J5.1, J13.2, K1.13, SW2.2 (B)
/Safety Relay/RELAY_CTRL: J11.1, Q3.2 (B), R9.1
/Safety Relay/START_SENSE: J11.2, R8.1, SW3.2 (B)
GNDREF: J10.3, JP1.1 (A), Q3.1 (E), R8.2, R9.2; also elsewhere on the board
unnamed: D4.2 (A), J14.1, JP1.2 (B), K1.A2, Q3.3 (C)

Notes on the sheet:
Sefety Relay
Connectors Pinout

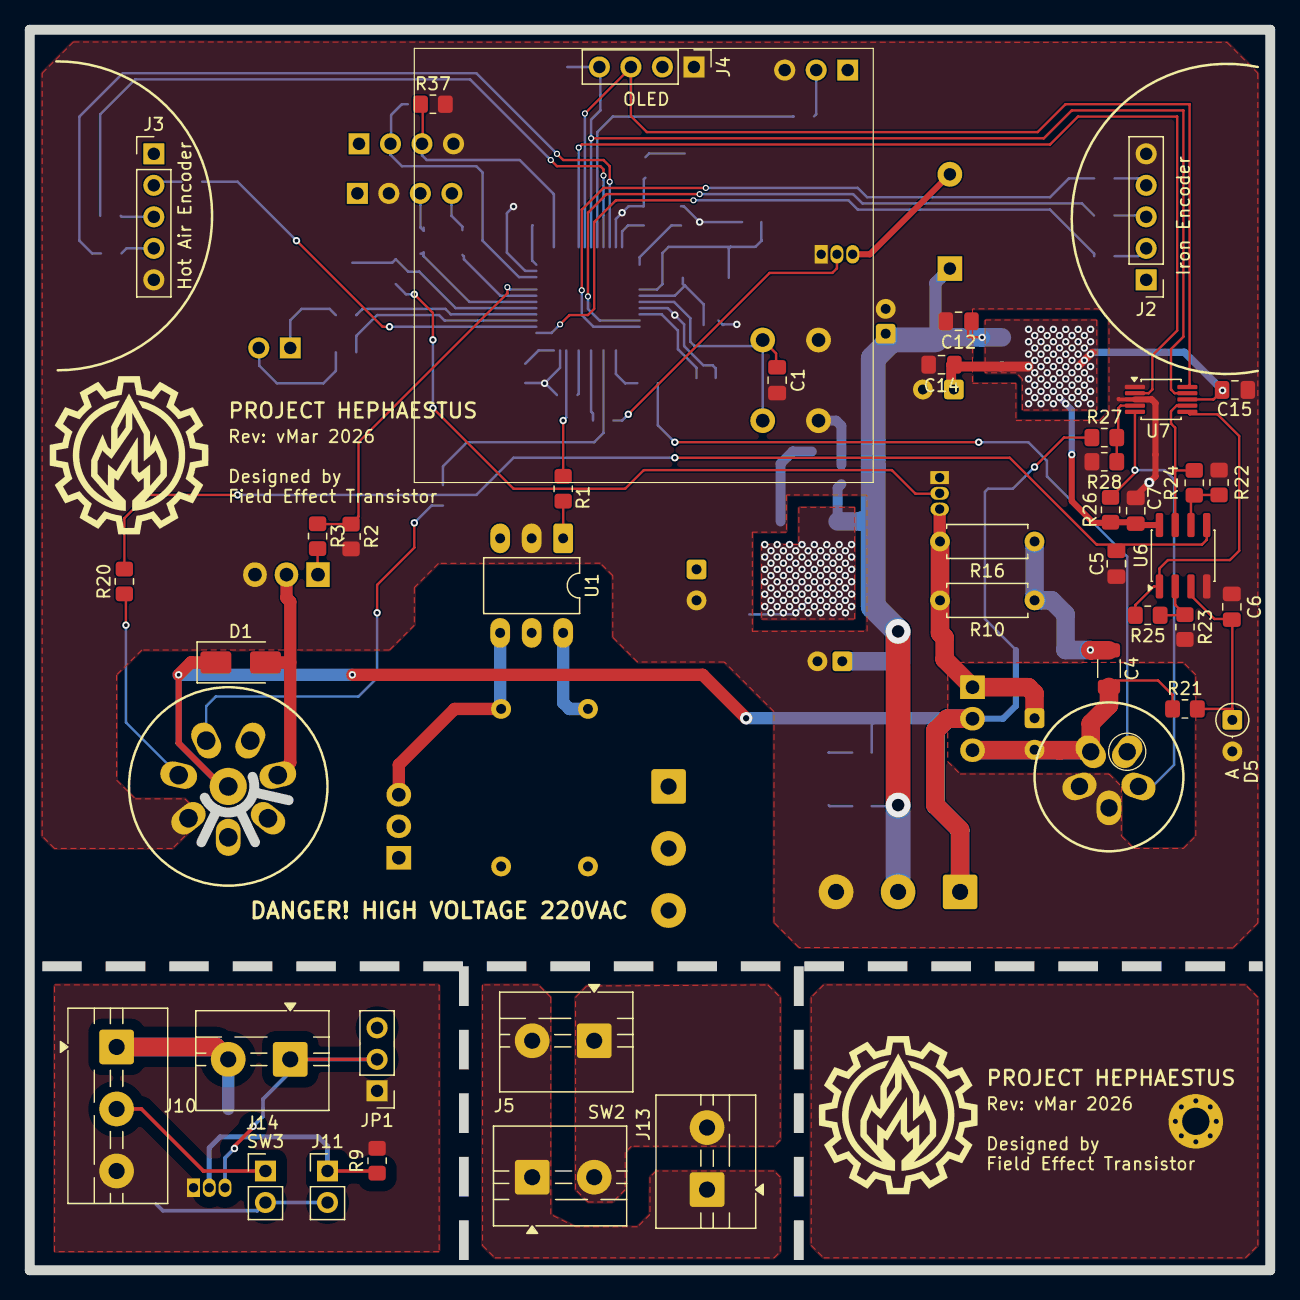
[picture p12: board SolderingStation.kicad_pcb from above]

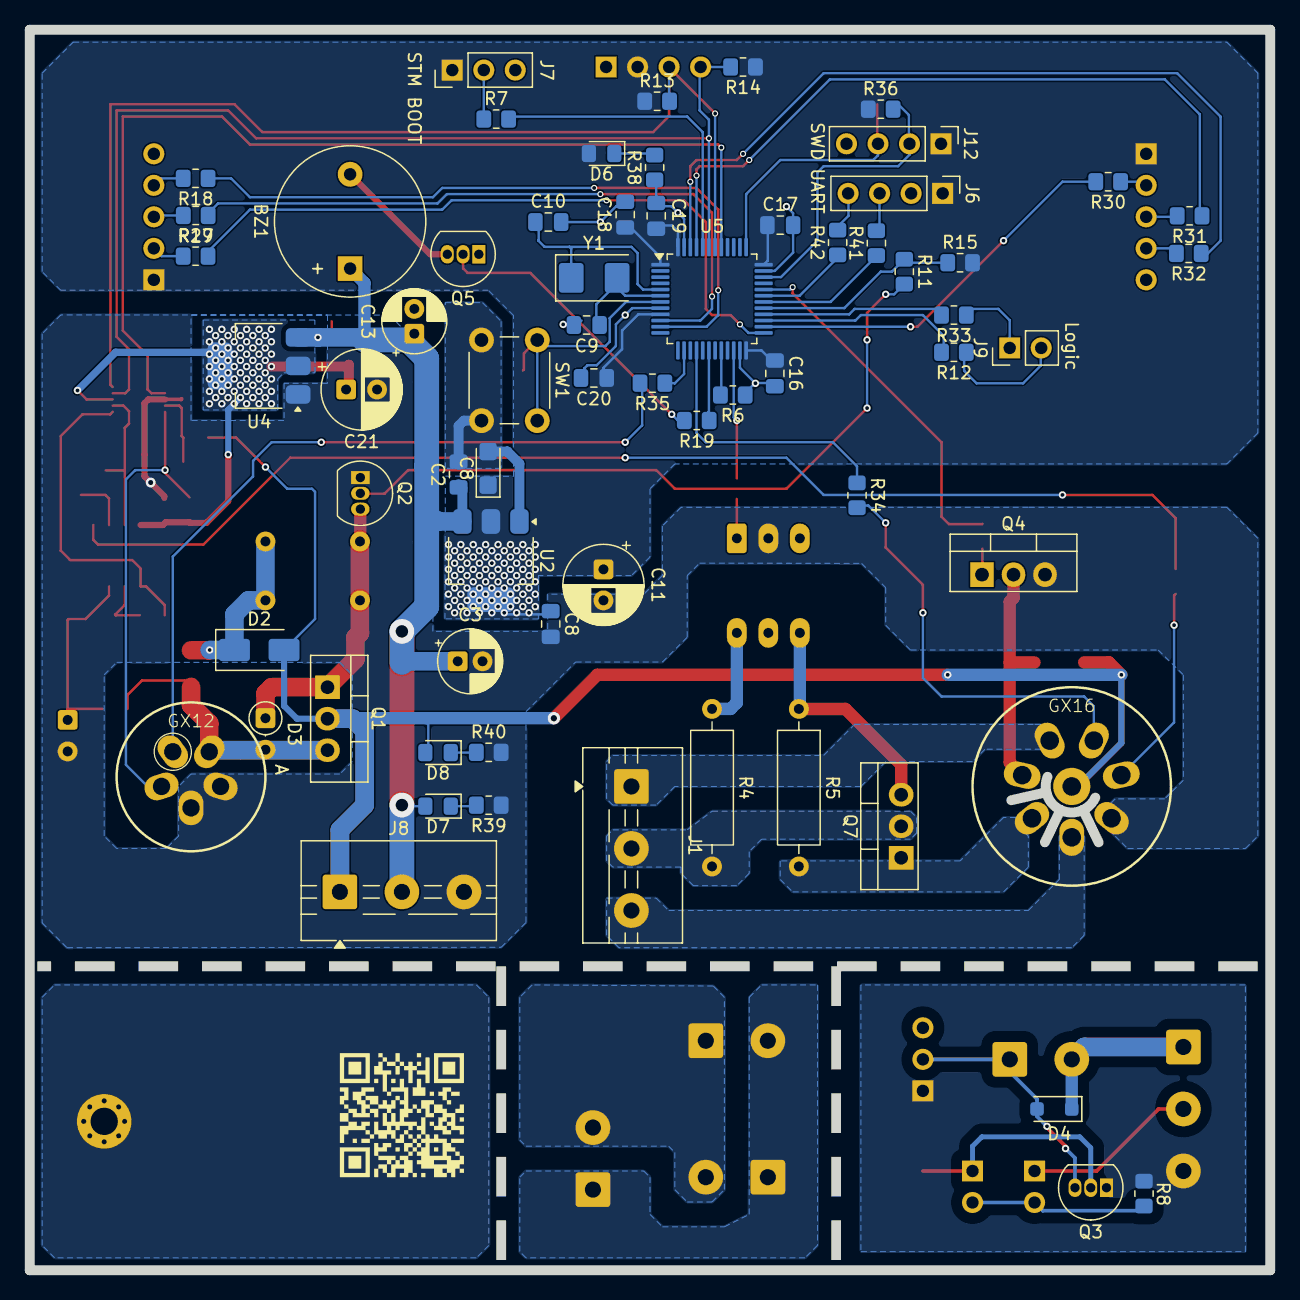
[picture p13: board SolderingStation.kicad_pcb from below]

Board: 2 copper layers, 100.0 x 100.0 mm, 106 parts (66 on the bottom side), 78 nets.

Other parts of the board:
C8#2: 0.1u; C_0805_2012Metric_Pad1.18x1.45mm_HandSolder

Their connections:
/3V3_STM: C8#2.1; also elsewhere on the board
GNDREF: C8#2.2; also elsewhere on the board

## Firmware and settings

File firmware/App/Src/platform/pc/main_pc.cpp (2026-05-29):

// App/Src/platform/pc/main_pc.cpp
#include <iostream>
#include <cstdio>
#include <SDL2/SDL.h>
#include <pthread.h> 

#include "FreeRTOS.h"
#include "task.h"

#include "platform/pc/sdl_context.hpp"
#include "interfaces/IAdc.hpp"
#include "interfaces/IPwm.hpp"
#include "interfaces/IDigitalPin.hpp"
#include "interfaces/IEncoder.hpp"
#include "interfaces/ILogSink.hpp"

#include "logic/station_manager.hpp"
#include "system/logger/logger.hpp"
#include "system/i2c_arbiter.hpp"

#include "platform/pc/file_storage.hpp"
#include "platform/pc/hal_mock.hpp"

SemaphoreHandle_t Hephaestus::i2c1Mutex = nullptr;
extern "C" uint32_t HAL_GetTick(); 

Hephaestus::SdlContext sdlContext;

namespace Hephaestus {

    class SdlPinIron : public IDigitalPin {
        bool isActive() override { return sdlContext.isIronPressed(); } 
    };
    class SdlPinAir : public IDigitalPin {
        bool isActive() override { return sdlContext.isAirPressed(); } 
    };
    class SdlEncoderIron : public IEncoder {
        void init() override {}
        EncoderResult getSteps() override { 
            int16_t diff = sdlContext.getIronEncDiff();
            return {diff, diff}; 
        }
    };
    class SdlEncoderAir : public IEncoder {
        void init() override {}
        EncoderResult getSteps() override { 
            int16_t diff = sdlContext.getAirEncDiff();
            return {diff, diff}; 
        }
    };

    class MockAdc : public IAdc {
    public:
        float simulatedTempIron = 25.0f;
        float simulatedTempAir  = 25.0f;

        float readVoltage(uint8_t channel) override {
            if (channel == 2) { // IRON TC (Gain 201)
                return (simulatedTempIron - 25.0f) * 0.041f * 201.0f / 1000.0f;
            }
            if (channel == 3) { // AIR TC (Gain 101)
                return (simulatedTempAir - 25.0f) * 0.041f * 101.0f / 1000.0f;
            }
            if (channel == 0) return 2.18f; // PSU
            if (channel == 1) return 1.65f; // NTC (25C)
            
            return 0.0f;
        }

        void applyHeat(float ironDuty, float airDuty, float dt) {
            const float IRON_HEAT_RATE = 150.0f;
            const float AIR_HEAT_RATE  = 80.0f;
            
            const float IRON_COOL_RATE = 0.5f;
            const float AIR_COOL_RATE  = 0.3f;
            
            const float AMBIENT_TEMP = 25.0f;

            float ironHeat = (ironDuty / 100.0f) * IRON_HEAT_RATE;
            float ironCool = (simulatedTempIron - AMBIENT_TEMP) * IRON_COOL_RATE;
            
            simulatedTempIron += (ironHeat - ironCool) * dt;
            if (simulatedTempIron < AMBIENT_TEMP) simulatedTempIron = AMBIENT_TEMP;

            float airHeat = (airDuty / 100.0f) * AIR_HEAT_RATE;
            float airCool = (simulatedTempAir - AMBIENT_TEMP) * AIR_COOL_RATE;
            
            simulatedTempAir += (airHeat - airCool) * dt;
            if (simulatedTempAir < AMBIENT_TEMP) simulatedTempAir = AMBIENT_TEMP;
        }
    };

    class MockPwm : public IPwm {
    public:
        float currentDuty = 0.0f;
        void setDutyCycle(float p) override { currentDuty = p; } 
        void enable(bool s) override { if(!s) currentDuty = 0.0f; }
        float getDutyCycle() const { return currentDuty; }
    };

    class ConsoleLogSink : public ILogSink {
        bool isReady() const override { return true; }
        void write(const uint8_t* d, size_t l) override { fwrite(d, 1, l, stdout); fflush(stdout); }
    };

    class SdlStandPinIron : public IDigitalPin {
        bool isActive() override { return sdlContext.isIronInHand(); } 
    };

    class SdlStandPinAir : public IDigitalPin {
        bool isActive() override { return !sdlContext.isAirInHand(); } 
    };

    class MockBuzzerPwm : public IPwm {
    public:
        void setDutyCycle(float p) override {} 
        void enable(bool s) override { 
            if (s) std::cout << "\a";
        }
        float getDutyCycle() const override { return 0.0f; }
    };
}

// --- ІНСТАНЦІЮВАННЯ СИСТЕМИ ---
static Hephaestus::MockAdc        mockAdc;
static Hephaestus::SdlPinIron     pinIron;
static Hephaestus::SdlPinAir      pinAir;
static Hephaestus::SdlEncoderIron encIron;
static Hephaestus::SdlEncoderAir  encAir;
static Hephaestus::MockPwm        ironPwm;
static Hephaestus::MockPwm        airPwm;
static Hephaestus::MockPwm        airFanPwm;
static Hephaestus::MockBuzzerPwm  buzzerPwm;
static Hephaestus::ConsoleLogSink consoleSink;
static Hephaestus::SdlStandPinIron standIron;
static Hephaestus::SdlStandPinAir  standAir;

static Hephaestus::FileStorage    storage;

static Hephaestus::StationManager station(
    storage, mockAdc, pinIron, pinAir, standIron, standAir, encIron, encAir, ironPwm, airPwm, airFanPwm, buzzerPwm
);

// --- ЗАДАЧІ FREERTOS ---
void appLoopTask(void*) {
    for(;;) {
        station.tickInput(HAL_GetTick());
        
        // Гріємо віртуальні паяльник і фен!
        mockAdc.applyHeat(ironPwm.getDutyCycle(), airPwm.getDutyCycle(), 0.015f);
        
        vTaskDelay(pdMS_TO_TICKS(15));
    }
}

void displayTask(void*) {
    station.initDisplay();
    for(;;) {
        station.tickDisplay();
        vTaskDelay(pdMS_TO_TICKS(80)); 
    }
}

void* rtosThreadRunner(void* arg) {
    std::cout << "Starting FreeRTOS Scheduler in Background Thread...\n";
    vTaskStartScheduler();
    return nullptr;
}

void controlLoopTask(void*) {
    for(;;) {
        uint32_t tick = HAL_GetTick();
        
        station.tickControl(tick);
        
        mockAdc.applyHeat(ironPwm.getDutyCycle(), airPwm.getDutyCycle(), 0.05f);

        vTaskDelay(pdMS_TO_TICKS(50));
    }
}

void safetyTask(void*) {
    for(;;) {
        // У ПК-версії немає реального IWDG, але ми імітуємо виклик
        HAL_IWDG_Refresh(&hiwdg);

        if (station.hasSystemError()) {
            Hephaestus::Logger::fatal("SAFETY", "CRITICAL FAULT! SIMULATOR POWER KILLED!");
            
            ironPwm.enable(false);
            airPwm.enable(false);
            airFanPwm.enable(false);
            buzzerPwm.enable(true); // У консолі буде пищати "\a" нескінченно

            while(1) { 
                vTaskDelay(pdMS_TO_TICKS(100)); // На ПК треба спати, щоб не повісити потік ОС
            }
        }

        vTaskDelay(pdMS_TO_TICKS(20));
    }
}

int main() {
    std::cout << "Starting Hephaestus FreeRTOS Simulator...\n";
    std::cout << "[UP/DOWN, ENTER] - Iron | [W/S, SPACE] - Air\n\n";
    std::cout << "[UP/DOWN, ENTER, I] - Iron | [W/S, SPACE, A] - Air\n\n";

    Hephaestus::Logger::init();
    Hephaestus::Logger::addSink(&consoleSink);

    sdlContext.init();
    station.init();

    xTaskCreate(Hephaestus::Logger::taskLoop, "Logger",  configMINIMAL_STACK_SIZE, nullptr, 1, nullptr);
    xTaskCreate(displayTask,                  "Display", configMINIMAL_STACK_SIZE, nullptr, 2, nullptr);
    xTaskCreate(appLoopTask,                  "Input",   configMINIMAL_STACK_SIZE, nullptr, 3, nullptr);
    xTaskCreate(controlLoopTask,              "Control", configMINIMAL_STACK_SIZE, nullptr, 4, nullptr);
    xTaskCreate(safetyTask,                   "Safety",  configMINIMAL_STACK_SIZE, nullptr, 5, nullptr);

    pthread_t rtosThread;
    pthread_create(&rtosThread, nullptr, rtosThreadRunner, nullptr);

    sdlContext.runLoop(); 

    return 0;
}

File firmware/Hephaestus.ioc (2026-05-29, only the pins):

Mcu.UserName=STM32F103C8Tx
PA0-WKUP.Signal=S_TIM2_CH1_ETR
PA1.Signal=S_TIM2_CH2
PA10.Signal=USART1_RX
PA11.Signal=S_TIM1_CH4
PA13.Signal=SYS_JTMS-SWDIO
PA14.Signal=SYS_JTCK-SWCLK
PA4.Signal=GPXTI4
PA6.Signal=GPXTI6
PA8.Signal=S_TIM1_CH1
PA9.Signal=USART1_TX
PB0.Signal=S_TIM3_CH3
PB11.Signal=GPIO_Output
PB12.Signal=GPXTI12
PB13.Signal=GPXTI13
PB14.Signal=GPIO_Input
PB15.Signal=GPIO_Output
PB5.Signal=GPXTI5
PB6.Signal=S_TIM4_CH1
PB7.Signal=S_TIM4_CH2
PB8.Signal=I2C1_SCL
PB9.Signal=I2C1_SDA
PC13-TAMPER-RTC.Signal=GPIO_Output
PD0-OSC_IN.Signal=RCC_OSC_IN
PD1-OSC_OUT.Signal=RCC_OSC_OUT

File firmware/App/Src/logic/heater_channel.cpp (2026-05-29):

// App/Src/logic/heater_channel.cpp
#include "logic/heater_channel.hpp"
#include "system/logger/logger.hpp"

namespace Hephaestus {

    HeaterChannel::HeaterChannel(
        const char* name,
        IPwm& pwmDriver,
        int16_t defaultTemp,
        int16_t minTemp,
        int16_t maxTemp,
        int16_t sleepTemp,
        float kp,
        float ki,
        float kd,
        uint16_t sleepTimeoutSec 
    ) : _name(name), 
        _pwmDriver(pwmDriver), 
        _targetTemp(defaultTemp), 
        _currentTemp(0), 
        _pwmDuty(0.0f), 
        _state(ChannelState::Off),
        _minTemp(minTemp), 
        _maxTemp(maxTemp), 
        _sleepTemp(sleepTemp),
        _sleepTimeoutSec(sleepTimeoutSec),
        _idleTimeSec(0.0f),    
        _watchdogTimerSec(0.0f),
        _watchdogCheckpointTemp(0),
        _pid(kp, ki, kd, 0.0f, 100.0f)
    {
        if (_targetTemp < _minTemp) _targetTemp = _minTemp;
        if (_targetTemp > _maxTemp) _targetTemp = _maxTemp;
        _pwmDriver.setDutyCycle(0.0f);
    }

    void HeaterChannel::toggleState() {
        if (_state == ChannelState::Error) {
            Logger::warn("LOGIC", "[%s] Cannot toggle: Error State! Reset required.", _name);
            return;
        }

        if (_state == ChannelState::Off || _state == ChannelState::Sleep) {
            setState(ChannelState::Active);
        } else {
            setState(ChannelState::Off);
        }
    }

    void HeaterChannel::setState(ChannelState newState) {
        if (_state == newState) return;
        
        if (newState == ChannelState::Active) {
            _pid.reset(); 
            _watchdogTimerSec = 0.0f;
        }
        
        _state = newState;

        const char* stateStr = "UNKNOWN";
        switch (_state) {
            case ChannelState::Off:    stateStr = "OFF"; break;
            case ChannelState::Active: stateStr = "ACTIVE"; break;
            case ChannelState::Sleep:  stateStr = "SLEEP"; break;
            case ChannelState::Error:  stateStr = "ERROR"; break;
        }

        Logger::info("LOGIC", "[%s] State changed to -> %s", _name, stateStr);
    }

    void HeaterChannel::changeTargetTemp(int16_t delta) {
        setTargetTemp(_targetTemp + delta);
    }

    void HeaterChannel::setTargetTemp(int16_t newTemp) {
        int16_t oldTemp = _targetTemp;

        _targetTemp = newTemp;
        if (_targetTemp < _minTemp) _targetTemp = _minTemp;
        if (_targetTemp > _maxTemp) _targetTemp = _maxTemp;

        if (oldTemp != _targetTemp) {
            Logger::info("LOGIC", "[%s] Target Temp: %d C", _name, _targetTemp);
        }
    }

    // --- ЛОГІКА ТЕРМАЛЬНОГО ЗАХИСТУ ---
    void HeaterChannel::checkThermalWatchdog(float dt) {
        // Якщо система "жарить" на високій потужності (> 80%)
        if (_pwmDuty >= WD_PWM_THRESHOLD) {
            
            // Захоплюємо температуру на початку відліку
            if (_watchdogTimerSec == 0.0f) {
                _watchdogCheckpointTemp = _currentTemp;
            }

            _watchdogTimerSec += dt;

            // Коли таймер вийшов
            if (_watchdogTimerSec >= WD_TIMEOUT_SEC) {
                int16_t tempRise = _currentTemp - _watchdogCheckpointTemp;

                // Якщо температура не зросла на заданий мінімум - це АВАРІЯ
                if (tempRise < WD_MIN_TEMP_RISE) {
                    Logger::fatal("SAFETY", "[%s] THERMAL RUNAWAY DETECTED! Shutting down.", _name);
                    setState(ChannelState::Error);
                } else {
                    // Температура росте нормально. Скидаємо таймер і чекпойнт.
                    _watchdogTimerSec = 0.0f;
                }
            }
        } else {
            // Якщо потужність падає нижче 80% - ПІД працює нормально, знімаємо "підозру"
            _watchdogTimerSec = 0.0f;
        }
    }

    void HeaterChannel::updateControlLoop(float dt) {
        if (_state == ChannelState::Off || _state == ChannelState::Error) {
            _pwmDuty = 0.0f;
            _pwmDriver.setDutyCycle(_pwmDuty);
            return;
        }

        if (_state == ChannelState::Active) {
            _idleTimeSec += dt;
            if (_sleepTimeoutSec > 0 && _idleTimeSec >= _sleepTimeoutSec) {
                Logger::info("LOGIC", "[%s] Auto-Sleep triggered due to inactivity", _name);
                setState(ChannelState::Sleep);
            }
        }

        int16_t activeTarget = (_state == ChannelState::Sleep) ? _sleepTemp : _targetTemp;
        
        _pwmDuty = _pid.compute((float)activeTarget, (float)_currentTemp, dt);

        checkThermalWatchdog(dt);

        if (_state == ChannelState::Error) {
            _pwmDuty = 0.0f;
        }

        _pwmDriver.setDutyCycle(_pwmDuty);
    }

} // namespace Hephaestus

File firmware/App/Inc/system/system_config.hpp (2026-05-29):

// App/Inc/system/system_config.hpp
#pragma once
#include <cstdint>

namespace Hephaestus {

    struct SensorConfig {
        //  --- Попередні налаштування для PSU та NTC
        float psuDividerRatio = 11.0f;     
        float psuVoltageOffset = 0.0f;     
        float ntcReferenceVoltage = 3.3f;  
        float ntcTopResistor = 10000.0f;   
        float ntcNominalRes = 10000.0f;    
        float ntcNominalTemp = 298.15f;    
        float ntcBeta = 3950.0f;           

        //  --- Калібрування Паяльника (T12) ---
        float ironOpAmpGain = 201.0f;      
        float ironOpAmpOffsetV = 0.0f;     
        float ironTcSensitivity = 0.041f;  
        
        // ПІД КОЕФІЦІЄНТИ (Розраховані за Зіглером-Нікольсом у Розділі 1)
        float ironKp = 6.0f;
        float ironKi = 30.534f;
        float ironKd = 0.295f;

        // --- Калібрування Термофена (Air) ---
        float airOpAmpGain = 101.0f;       
        float airOpAmpOffsetV = 0.0f;      
        float airTcSensitivity = 0.041f;   
        
        // ПІД КОЕФІЦІЄНТИ ДЛЯ ФЕНА
        float airKp = 2.0f;
        float airKi = 5.0f;
        float airKd = 0.1f;

        // --- Налаштування Сну ---
        uint16_t ironSleepTimeoutSec = 180; // 3 хвилини (180 сек) бездіяльності для паяльника
        uint16_t airSleepTimeoutSec = 300;  // 5 хвилин (300 сек) бездіяльності для фена

        // Точки калібрування паяльника
        float ironCalibRaw[3]  = { 200.0f, 300.0f, 400.0f };
        float ironCalibReal[3] = { 200.0f, 300.0f, 400.0f };

        // Точки калібрування фена
        float airCalibRaw[3]   = { 200.0f, 300.0f, 400.0f };
        float airCalibReal[3]  = { 200.0f, 300.0f, 400.0f };
    };

    struct UserSettings {
        int16_t ironTargetTemp = 300; // Цільова температура паяльника
        int16_t airTargetTemp  = 300; // Цільова температура фена
        int16_t airFanSpeed    = 50;  // Швидкість вентилятора фена (у відсотках)
    };

    struct SystemConfig {
        SensorConfig sensors;
        UserSettings user;
    };

} // namespace Hephaestus

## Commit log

2026-01-16 first steps
    Soldering Iron & Hot Air pinout added
    ADC logic added
    [SolderingStation.kicad_pcb, SolderingStation.kicad_sch]
2026-01-18 fix: ADC
    24V converting fix
    PWD_I resistor fix
    [SolderingStation.kicad_sch]
2026-01-18 feature: heater switch
    [SolderingStation.kicad_sch]
2026-01-19 feature: fan logic
    [SolderingStation.kicad_sch]
2026-01-20 feature: basic nodes
    [SolderingStation.kicad_sch]
2026-02-04 peripherals done
    [ADC.kicad_sch, MUG.kicad_sch, SolderingStation.kicad_sch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]
2026-02-11 feature: safety relay
    [SolderingStation.kicad_sch, safetyRelay.kicad_sch]
2026-02-24 mvp
    features:
    Logic Power Supply
    Safety Relay
    Main Unit
    [ADC.kicad_sch, LogicPowerSupply.kicad_sch, MUG.kicad_sch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]
2026-03-07 starting pcb
    [ADC.kicad_sch, LogicPowerSupply.kicad_sch, MUG.kicad_sch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]
2026-03-09 fast commit
    [SolderingStation.kicad_pcb, SolderingStation.kicad_sch]
2026-03-15 pcb mvp
    [ADC.kicad_sch, LogicPowerSupply.kicad_sch, MUG.kicad_sch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]
2026-05-15 stm32 init
2026-05-15 feat: button
2026-05-19 feat(system): button
2026-05-19 feature(system): encoder
2026-05-28 feat: introduce Hardware Abstraction Layer and PC Simulator
    - Refactored architecture using Dependency Injection (IAdc, IEncoder, etc.)
    - Added PC Simulator with SDL2 for testing UI and logic on Linux
    - Decoupled u8g2 display manager from hardware I2C
    - Centralized StationManager to handle business logic
    - Introduced thread-safe SDL event loop for input simulation
2026-05-28 feat(logic): integrate PID controller into heater channel control loop
2026-05-28 feat(ui): implement interactive screens (Menu, PID, System Info) and routing
2026-05-29 feat(core): separate control loop to RTOS task and implement TDM for ADC
2026-05-29 feat: implement auto-sleep via stand sensors and hot air fan control
2026-05-29 feat(core): add 3-point temperature calibration and buzzer feedback
    [app.cpp, main_pc.cpp, math_sensors.hpp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]
2026-05-29 refactor(hw): remap PWM pins and introduce software PWM for 220V heater
2026-05-29 feat(ui): add calibration screen skeleton to main menu
2026-05-29 feat(safety): implement hardware watchdog and critical fault power kill

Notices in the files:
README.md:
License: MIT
